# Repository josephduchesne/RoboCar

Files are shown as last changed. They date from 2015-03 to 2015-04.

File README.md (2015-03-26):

# RoboCar

A robot car that uses the following:

[Hardware](../../wiki/Bill-of-Materials)

Note: When cloning use `git clone --recursive git@github.com:josephduchesne/RoboCar.git` to also checkout the usb_cam submodule.

### Third Party Licenses:

 - 3D_Prints/PanTilt is third party, created by Javier Bernal Mayordomo, Miguel Manzano Olmos, and Arturo Serna León under a [Creative Commons - Attribution - Share Alike](http://creativecommons.org/licenses/by-sa/3.0/) license
 - ROS_Workspace/src/usb_cam is third party and by Robert Bosch LLC. under a [BSD licence](https://github.com/bosch-ros-pkg/usb_cam/blob/develop/LICENSE)
 - ROS_Workspace/src/differential_drive is third party and by Jon Stephan under a [GPLv3 license](http://www.gnu.org/licenses/gpl-3.0.html)

### License

For all files not otherwise noted in Third Party Licenses or by license information contained within the files are licensed under:

The MIT License (MIT)

Copyright (c) 2015 Joseph Duchesne

Permission is hereby granted, free of charge, to any person obtaining a copy
of this software and associated documentation files (the "Software"), to deal
in the Software without restriction, including without limitation the rights
to use, copy, modify, merge, publish, distribute, sublicense, and/or sell
copies of the Software, and to permit persons to whom the Software is
furnished to do so, subject to the following conditions:

The above copyright notice and this permission notice shall be included in
all copies or substantial portions of the Software.

THE SOFTWARE IS PROVIDED "AS IS", WITHOUT WARRANTY OF ANY KIND, EXPRESS OR
IMPLIED, INCLUDING BUT NOT LIMITED TO THE WARRANTIES OF MERCHANTABILITY,
FITNESS FOR A PARTICULAR PURPOSE AND NONINFRINGEMENT. IN NO EVENT SHALL THE
AUTHORS OR COPYRIGHT HOLDERS BE LIABLE FOR ANY CLAIM, DAMAGES OR OTHER
LIABILITY, WHETHER IN AN ACTION OF CONTRACT, TORT OR OTHERWISE, ARISING FROM,
OUT OF OR IN CONNECTION WITH THE SOFTWARE OR THE USE OR OTHER DEALINGS IN
THE SOFTWARE.

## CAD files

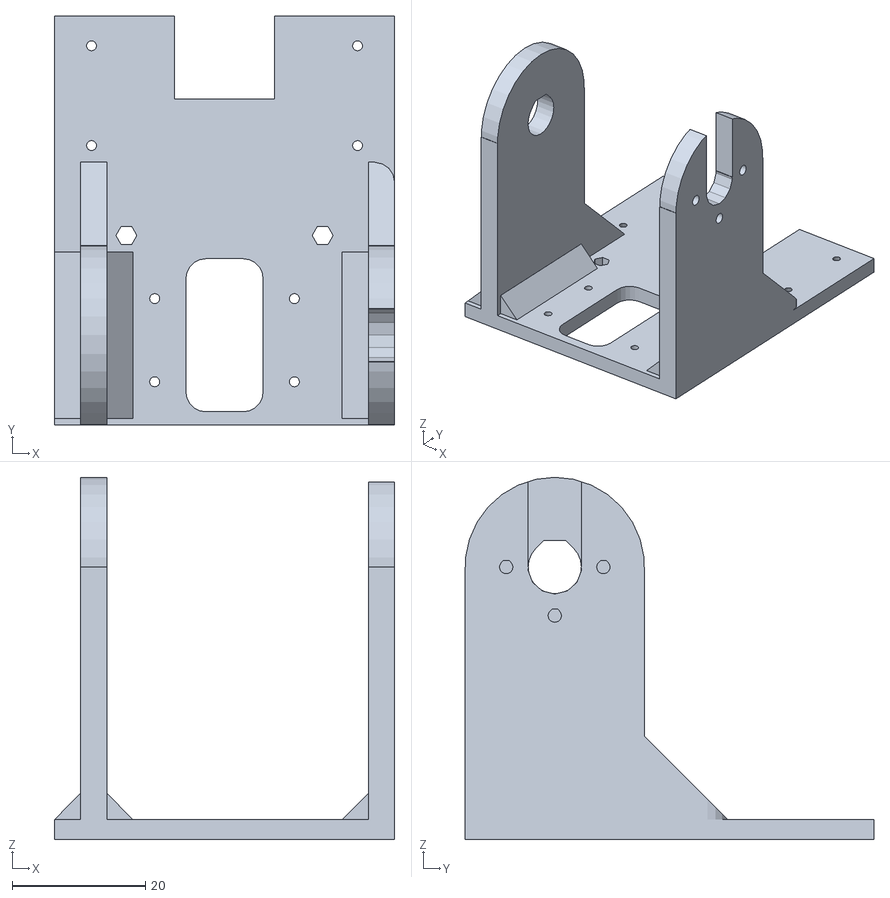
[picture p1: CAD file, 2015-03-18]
3D_Prints/PanTilt/head.stl
51.2 x 61.5 x 54.5

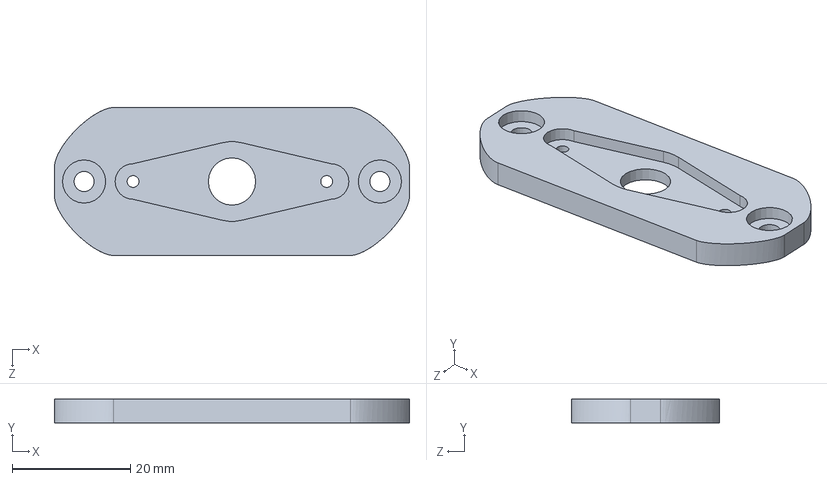
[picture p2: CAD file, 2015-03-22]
3D_Prints/PanTiltBase/BaseTop.SLDPRT
60.0 x 4.00 x 25.0 mm

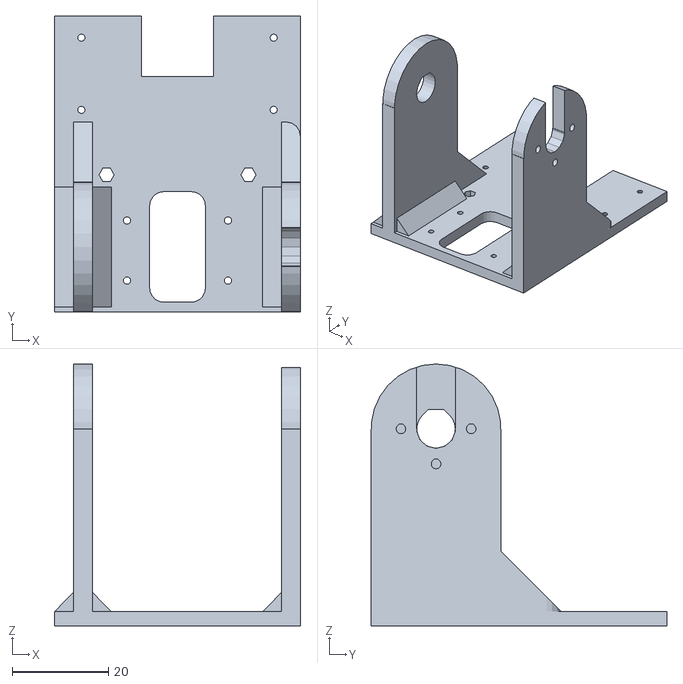
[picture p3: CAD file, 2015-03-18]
3D_Prints/PanTilt/head_fixed.stl
51.2 x 61.5 x 54.5

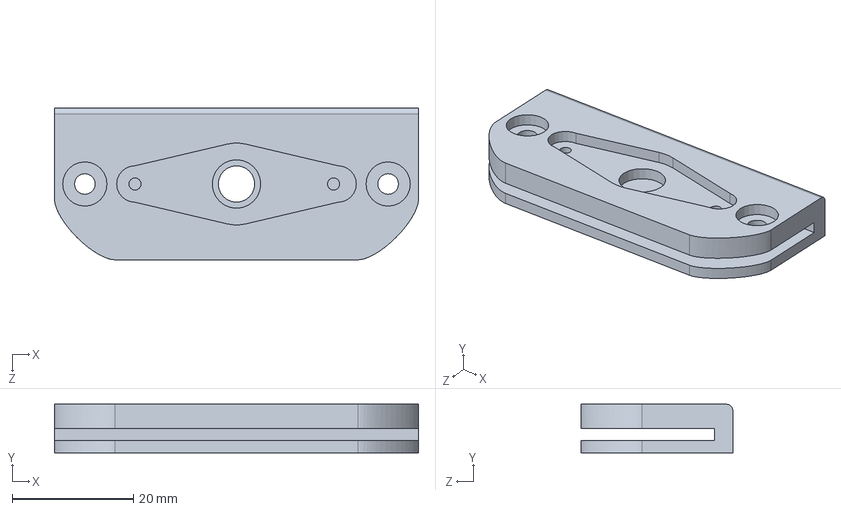
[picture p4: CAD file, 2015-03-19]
3D_Prints/PanTiltBase/Base.SLDPRT
60.0 x 8.00 x 25.0 mm

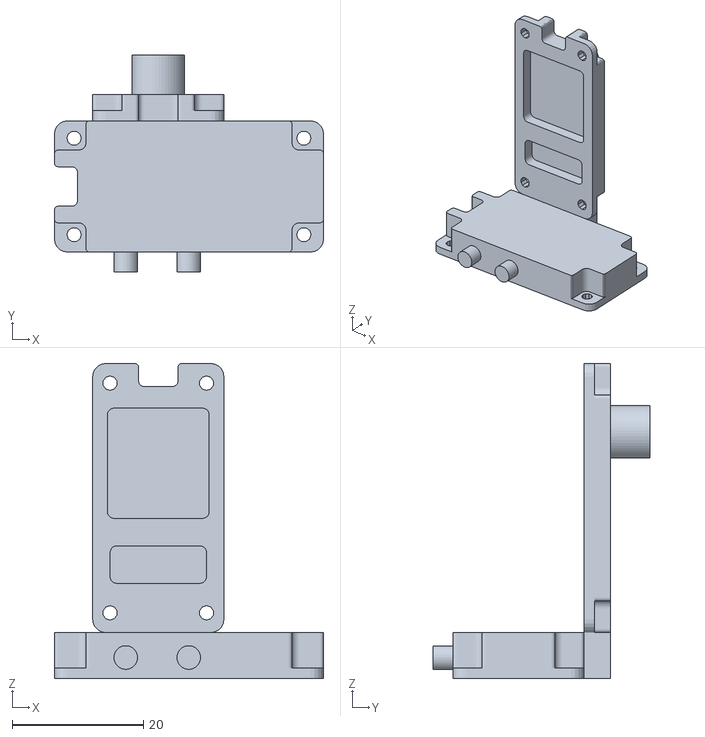
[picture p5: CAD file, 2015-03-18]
3D_Prints/PanTilt/servo_fixed.stl
41.0 x 33.0 x 48.0

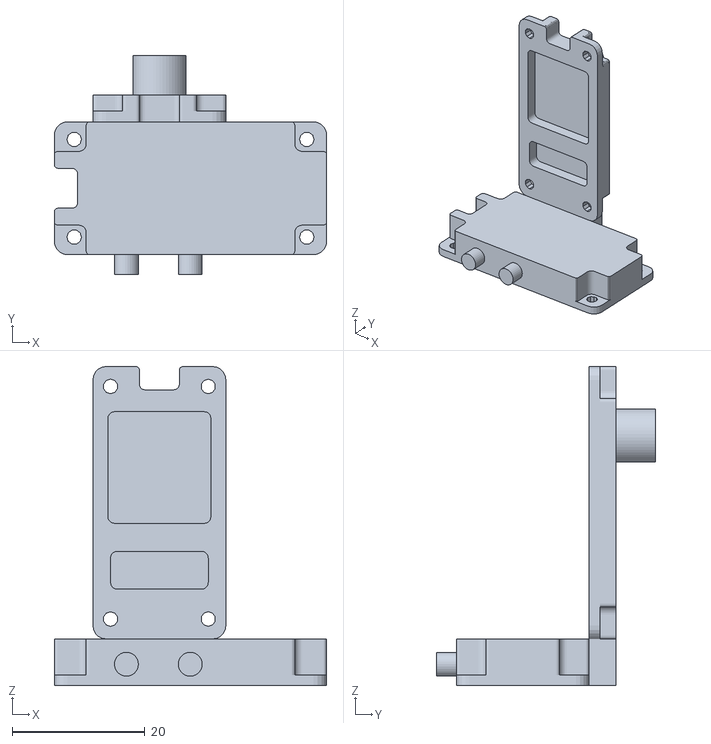
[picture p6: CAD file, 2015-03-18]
3D_Prints/PanTilt/servo.stl
41.0 x 33.0 x 48.0

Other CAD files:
3D_Prints/PanTiltBase/Base.STL
3D_Prints/PanTiltBase/BaseTop.STL

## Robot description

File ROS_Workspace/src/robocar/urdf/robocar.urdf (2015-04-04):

<robot name="robocar">

  <!-- The base platform -->
  <link name="base_link">
    <visual> <!-- Platform top -->
      <origin xyz="0 0 0.079"/>
      <geometry>
        <box size="0.200 0.176 0.002"/>
      </geometry>
      <material name="grey"><color rgba="0.5 0.5 0.5 1"/></material>
    </visual>

    <visual> <!-- platform bottom -->
      <origin xyz="0 0 0.017"/>
      <geometry>
        <box size="0.200 0.113 0.002"/>
      </geometry>
      <material name="dark"/>
    </visual>
    <visual><origin xyz="0.115 0 0.017"/><geometry><box size="0.03 0.18 0.002" /></geometry><material name="dark"/></visual>

    <!-- Sides -->
    <visual><origin xyz="-.066 0.056 0.048"/><geometry><box size="0.04 0.002 0.062" /></geometry><material name="dark"/></visual>
    <visual><origin xyz=".066 0.056 0.048"/><geometry><box size="0.04 0.002 0.062" /></geometry><material name="dark"/></visual>
    <visual><origin xyz="-.066 -0.056 0.048"/><geometry><box size="0.04 0.002 0.062" /></geometry><material name="dark"/></visual>
    <visual><origin xyz=".066 -0.056 0.048"/><geometry><box size="0.04 0.002 0.062" /></geometry><material name="dark"/></visual>

    <visual>
      <origin xyz="0.08 -0.03 0.08" rpy="1.5708 0 1.5708"/>
      <material name="blue"><color rgba="0.1 0.1 1 1"/></material>
      <geometry>
        <mesh scale="0.001 0.001 0.001" filename="package://robocar/../../../3D_Prints/PanTiltBase/BaseTop.STL"/>
      </geometry>
    </visual>
  </link>

  <link name="sensor_arm">
    <visual>
      <origin xyz="-0.01085 0 0.023" />
      <material name="black"><color rgba="0.1 0.1 0.1 1"/></material>
      <geometry> 
        <box size="0.04 0.021 0.037"/>
      </geometry>
    </visual>
    <visual>
      <material name="blue"><color rgba="0.1 0.1 1 1"/></material>
      <origin xyz="-0.01085 0 0.04475" />
      <geometry> 
        <box size="0.04 0.021 0.0065"/>
      </geometry>
    </visual>
    <visual>
      <material name="black"/>
      <origin xyz="-0.006 0.0039 0.0655" />
      <geometry> 
        <box size="0.02 0.042 0.043"/>
      </geometry>
    </visual>
  </link>

  <link name="sensor_platform">
    <visual>
      <origin xyz="0.04 0 0" rpy="-1.5708 0 1.5708"/>
      <material name="blue"><color rgba="0.1 0.1 1 1"/></material>
      <geometry>
        <mesh scale="0.001 0.001 0.001" filename="package://robocar/../../../3D_Prints/PanTilt/head_fixed.stl"/>
      </geometry>
    </visual>
  </link>

  <link name="camera">
    <visual>
      <origin xyz="0 0 0.01" rpy="0 0 0"/>
      <material name="black"/>
      <geometry><cylinder length="0.02" radius="0.007"/></geometry>
    </visual>
  </link>

  <link name="rangefinder">
    <visual>
      <origin xyz="0.019 0.0146 0" rpy="0 -1.5708 0"/>
      <material name="black"/>
      <geometry><cylinder length="0.038" radius="0.0095"/></geometry>
    </visual>
    <visual>
      <origin xyz="0.019 -0.0146 0" rpy="0 -1.5708 0"/>
      <material name="black"/>
      <geometry><cylinder length="0.038" radius="0.0095"/></geometry>
    </visual>
    <visual>
      <origin xyz="0.01 0 0"/>
      <material name="black"/>
      <geometry><box size="0.014 0.04822 0.02"/></geometry>
    </visual>
  </link>

  <link name="laser_scanner">
  </link>

  <joint name="laser_scanner_fixed" type="fixed">
    <parent link="base_link"/>
    <child link="laser_scanner"/>
    <origin xyz="0.0925 0 0.121" rpy="3.141592 0 0"/> 
  </joint>

  <joint name="servo_yaw" type="revolute">
    <parent link="base_link"/>
    <child link="sensor_arm"/>
    <axis xyz="0 0 -1" />
    <limit lower="-1.57" upper="1.57" effort="1" velocity="1" />
    <origin xyz="0.0925 0 0.08"/> 
  </joint>

  <joint name="servo_pitch" type="revolute">
    <axis xyz="0 -1 0"/>
    <limit lower="-0.174" upper="1.745" effort="1" velocity="1"/>
    <parent link="sensor_arm"/>
    <child link="sensor_platform"/>
    <origin xyz="-.006 0.0014 0.078"/> 
  </joint>

  <joint name="camera_offset" type="fixed">
    <parent link="sensor_platform"/>
    <child link="camera"/>
    <origin xyz="0.04 0 0" rpy="-1.5708 0 -1.5708"/> 
  </joint>

  <joint name="rangefinder_offset" type="fixed">
    <parent link="sensor_platform"/>
    <child link="rangefinder"/>
    <origin xyz="0.04 0 -0.038"/> 
  </joint>

  <!-- Wheels Back -->
  <link name="wheel_back_left">
    <visual>
      <origin xyz="0 0 0" rpy="-1.5708 0 0"/>
      <material name="black"><color rgba="0.1 0.1 0.1 1"/></material>
      <geometry><cylinder length="0.018" radius="0.032"/></geometry>
    </visual>
  </link>

  <joint name="wheel_back_left_joint" type="continuous">
    <parent link="base_link"/>
    <axis xyz="0 1 0"/>
    <child link="wheel_back_left"/>
    <origin xyz="-0.0665 0.0745 0.032"/>
  </joint>

  <link name="wheel_back_right">
    <visual>
      <origin xyz="0 0 0" rpy="-1.5708 0 0"/>
      <material name="black"><color rgba="0.1 0.1 0.1 1"/></material>
      <geometry><cylinder length="0.018" radius="0.032"/></geometry>
    </visual>
  </link>

  <joint name="wheel_back_right_joint" type="continuous">
    <parent link="base_link"/>
    <axis xyz="0 1 0"/>
    <child link="wheel_back_right"/>
    <origin xyz="-0.0665 -0.0745 0.032"/>
  </joint>

  <!-- Wheels Front -->
  <link name="wheel_front_left">
    <visual>
      <origin xyz="0 0 0" rpy="-1.5708 0 0"/>
      <material name="black"><color rgba="0.1 0.1 0.1 1"/></material>
      <geometry><cylinder length="0.018" radius="0.032"/></geometry>
    </visual>
  </link>

  <joint name="wheel_front_left_joint" type="continuous">
    <mimic joint="wheel_back_left_joint"/>"
    <parent link="base_link"/>
    <axis xyz="0 1 0"/>
    <child link="wheel_front_left"/>
    <origin xyz="0.0665 0.0745 0.032"/>
  </joint>

  <link name="wheel_front_right">
    <visual>
      <origin xyz="0 0 0" rpy="-1.5708 0 0"/>
      <material name="black"><color rgba="0.1 0.1 0.1 1"/></material>
      <geometry><cylinder length="0.018" radius="0.032"/></geometry>
    </visual>
  </link>

  <joint name="wheel_front_right_joint" type="continuous">
    <mimic joint="wheel_back_right_joint"/>"
    <parent link="base_link"/>
    <axis xyz="0 1 0"/>
    <child link="wheel_front_right"/>
    <origin xyz="0.0665 -0.0745 0.032"/>
  </joint>

</robot>

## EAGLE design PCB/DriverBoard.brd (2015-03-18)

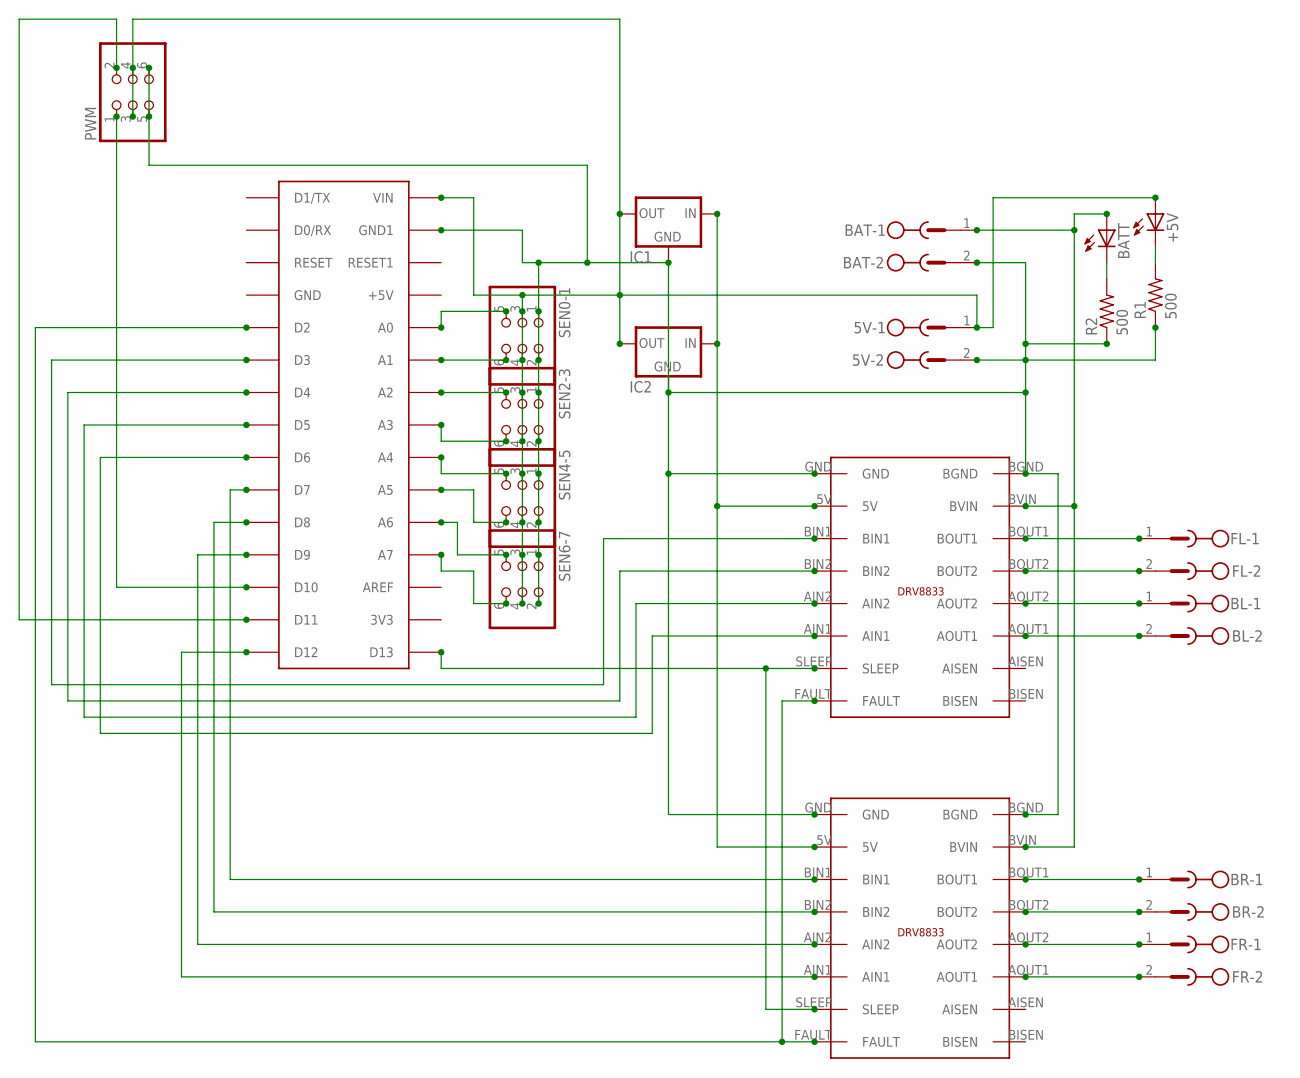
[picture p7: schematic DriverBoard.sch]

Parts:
5V: MSTBV2
+5V: LED5MM
BAT: MSTBV2
BATT: LED5MM
BL: MSTBV2
BR: MSTBV2
FL: MSTBV2
FR: MSTBV2
IC1, IC2: 78XXS
PWM: PINHD-2X3; 2X03
R1, R2: 500; 0207/10
SEN0-1, SEN2-3, SEN4-5, SEN6-7: PINHD-2X3; 2X03
U$1: ARDUINONANO; PDIP-32
U$2, U$3: DRV8833

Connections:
unnamed: 5V.2, BAT.2, IC1.GND, IC2.GND, PWM.5, PWM.6, R1.1, R2.1, SEN0-1.1, SEN0-1.2, SEN2-3.1, SEN2-3.2, SEN4-5.1, SEN4-5.2, SEN6-7.1, SEN6-7.2, U$1.GND1, U$2.BGND, U$2.GND, U$3.BGND, U$3.GND
unnamed: FL.1, U$2.BOUT1
unnamed: FL.2, U$2.BOUT2
unnamed: BL.1, U$2.AOUT2
unnamed: BL.2, U$2.AOUT1
unnamed: BR.1, U$3.BOUT1
unnamed: BR.2, U$3.BOUT2
unnamed: FR.1, U$3.AOUT2
unnamed: FR.2, U$3.AOUT1
unnamed: BAT.1, BATT.A, U$2.BVIN, U$3.BVIN
unnamed: U$1.D13, U$2.SLEEP, U$3.SLEEP
unnamed: IC1.IN, IC2.IN, U$2.5V, U$3.5V
unnamed: U$1.D3, U$2.BIN1
unnamed: U$1.D2, U$2.FAULT, U$3.FAULT
unnamed: U$1.D4, U$2.BIN2
unnamed: U$1.D5, U$2.AIN2
unnamed: U$1.D6, U$2.AIN1
unnamed: U$1.D7, U$3.BIN1
unnamed: U$1.D8, U$3.BIN2
unnamed: U$1.D9, U$3.AIN2
unnamed: U$1.D12, U$3.AIN1
unnamed: PWM.1, U$1.D10
unnamed: PWM.2, U$1.D11
unnamed: 5V.1, +5V.A, IC1.OUT, IC2.OUT, PWM.3, PWM.4, SEN0-1.3, SEN0-1.4, SEN2-3.3, SEN2-3.4, SEN4-5.3, SEN4-5.4, SEN6-7.3, SEN6-7.4, U$1.VIN
unnamed: SEN0-1.5, U$1.A0
unnamed: SEN0-1.6, U$1.A1
unnamed: SEN2-3.5, U$1.A2
unnamed: SEN2-3.6, U$1.A3
unnamed: SEN4-5.5, U$1.A4
unnamed: SEN4-5.6, U$1.A5
unnamed: SEN6-7.5, U$1.A6
unnamed: SEN6-7.6, U$1.A7
unnamed: BATT.K (C), R2.2
unnamed: +5V.K (C), R1.2

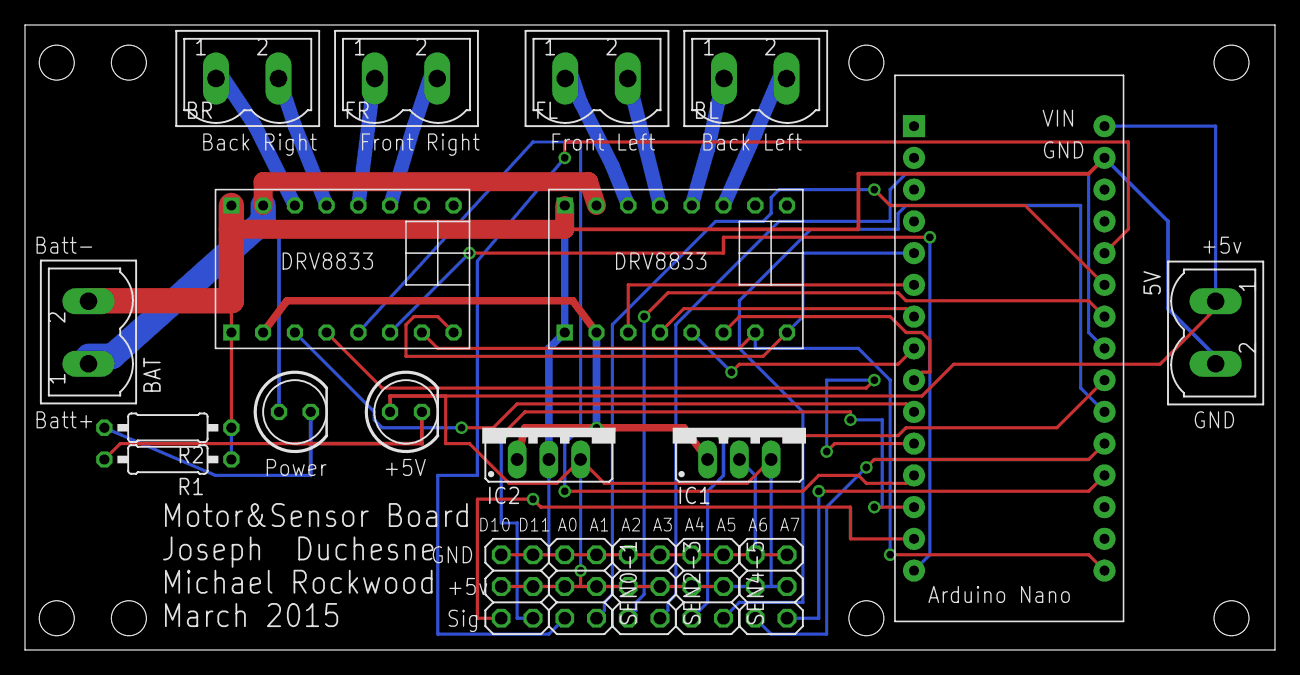
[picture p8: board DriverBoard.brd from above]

Board: 2 copper layers, 100.0 x 50.0 mm, 20 parts (0 on the bottom side), 34 nets.

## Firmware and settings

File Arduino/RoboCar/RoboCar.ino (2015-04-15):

/**
 * Main program
 * Handles serial I/O using a simple g-code inspired ASCII interface
 * Passes off specific motor, servo, and other sensor operations to other files.
 *
 * @author Joseph Duchesne
 */

/* --- incoming serial:  --- */
/* 
 in an any (but normally this) order:
 'L-100\n' to 'L100\n' - left speed
 'R-100\n' to 'R100\n' - right speed
 'M0\n' or 'M1\n' - mode: enable/disable things. LSB: motors, LSB+1: sensor sweep
 'P-10\n' to 'P100\n'  Pitch servo degree
 'Y-45\n' to '45\n' Yaw servo degree
 '#some text' - debugging comments
*/

/* --- outgoing serial: --- */
/* (only when compiled in OUTPUT_ASCII mode)
 in an any (but normally this) order:
 'L-32000\n' to 'L32000\n' the left wheel encoder ticks
 'R-32000\n' to 'R32000\n' the right wheel encoder ticks
 'P-10\n' to 'P100\n'  Pitch servo degree estimate @now
 'Y-45\n' to '45\n' Yaw servo degree estimate @now
 'D0\n' to 'D32000\n' - Rangefinder distance in millimeters
 '#some text' - debugging comments
*/

//decently fast serial
#define SERIAL_BAUD 115200
//ms to wait for more serial data
#define SERIAL_WAIT 2


//variables for controlling sensor data frequency
unsigned long lastOutput = 0;  //miliseconds since arduino start
const int timeBetweenOutputs = 100; //ms between outputting data

int range = 0;
int sensorOffset = 0;
boolean sensorSweep = false;
boolean flushData = false;
#define SENSOR_READINGS 15

// output mode
//#define OUTPUT_ASCII
#define OUTPUT_STRUCT

#ifdef OUTPUT_STRUCT
//note: these are 16 bit ints and should be int16 on PC
struct sensor_packet {
  int servo_pitch;
  int servo_yaw;
  int left_wheel_encoder;
  int right_wheel_encoder;
  int rangefinder_distance;
  int sweep[SENSOR_READINGS*2];
  char end1;
  char end2;
} __attribute__((__packed__));

struct sensor_packet sensorPacket;
#endif

/**
 * Setup function configures all pins, inits libs, resets values
 *
 * @return void
 */
void setup()
{
  motor_setup();
  
  servo_setup();
  
  rangefinder_setup();
  
  //Enable serial communication
  Serial.begin(SERIAL_BAUD); 
  //serial timeout on readBytesUntil()
  Serial.setTimeout(SERIAL_WAIT); //ms
  
  //Serial.println("#Started up");
}

/**
 * Main loop. Checks sensors and outputs readings.
 * 
 * @return void
 */
 
void loop()
{
  readRotaryEncoders(); //for motor data
  
  if (sensorSweep) {
    processSensorSweep();
  } else {
    range = getRange();
  }

  outputSensorData();
}


/**
 * Pseudo-interrupt for new serial data availability
 * Read user input, parse it, and pass that data to the appropriate functions.
 *
 * @return void
 */
void serialEvent(){
  char buff[16] = {0};
  char *data = buff+1;  //pointer offset by 1 to the buffer for the data segment of the command
  int intData;
  
  //read a command line inputs
  Serial.readBytesUntil('\n', buff, 32);
  switch (buff[0]) {
    case 'M': //mode
      intData = String(data).toInt();
      if (intData & 0b1) {  //LSB: 
        //Serial.println("#Motor command run: High");
        setMotorEnable(HIGH);
      } else {
        //Serial.println("#Motor command run: Low");
        setMotorEnable(LOW);
      }
      
      if (intData & 0b10 ) { //byte LSB+1: sensor sweep mode
        sensorSweep = true;
        
      } else {  //not in sweep mode
        sensorSweep = false;
        endSensorSweep();
      }
      break;
    case 'L': //left motor
      //intentional fallthrough to 'R'
    case 'R': //right motor
      intData = String(data).toInt();
      setMotors(buff[0], intData);
      break;
    case 'P': //pitch
      //intentional fallthrough to Yaw
    case 'Y': //yaw
      if ( sensorSweep ) break; //no manual servo movement during sensor sweep
      intData = String(data).toInt();
      setServo(buff[0], intData);
      break;
    case '#': //debug comments
      //we can ignore them
      break;
    default:
      if (buff[0]!='\0') {
        //Serial.print("#Unknown command: ");
        //Serial.println(buff);
      }
      break;
  }
}

/**
 * Tell the communication process to flush a reading
 *
 * @return  void
 */
void setFlushData(){
  flushData = true; 
}

/**
 * Output sensor data periodically via serial port
 *
 * @return void
 */
void outputSensorData(){
  //output sensor value every timeBetweenOutputs
  //or if we're full on sensor readings
  if (millis()-lastOutput < timeBetweenOutputs && sensorOffset<SENSOR_READINGS && !flushData) {
    return;
  }
  lastOutput = millis();
  flushData = false;
  
  #ifdef OUTPUT_ASCII
    //output estimated servo positions
    Serial.print('P');
    Serial.println(estimateServoPosition(0));
    Serial.print('Y');
    Serial.println(estimateServoPosition(1));
    
    //output wheel encoder data
    Serial.print('L');
    Serial.println(getWheelCounter(0));
    Serial.print('R');
    Serial.println(getWheelCounter(1));
    
    //output rangefinder distance data
    
    Serial.print('D');
    Serial.println(range);
  #endif
  
  #ifdef OUTPUT_STRUCT
    sensorPacket.servo_pitch = estimateServoPosition(0);
    sensorPacket.servo_yaw = estimateServoPosition(1);
    sensorPacket.left_wheel_encoder = getWheelCounter(0);
    sensorPacket.right_wheel_encoder = getWheelCounter(1);
    if (sensorSweep) {
      sensorPacket.rangefinder_distance = -sensorOffset;
    } else {
      sensorPacket.rangefinder_distance = range;
    }
    sensorPacket.end1 = 'E';
    sensorPacket.end2 = 'D';
    Serial.write((char *)&sensorPacket, sizeof(sensorPacket));
    
    //clear the sensor readings packet
    for (int i=0; i<SENSOR_READINGS*2;i++) {
      sensorPacket.sweep[i]=0;
    }
    sensorOffset = 0;
  #endif
  

}


/**
 * Write a sensor sweep reading to the sensor packet's data buffer
 *
 * @return void
 */
void setSensorData(float angle, int value){
  if( sensorSweep && sensorOffset<SENSOR_READINGS) {
    int angle_int = (int)(angle*100.0f);
    sensorPacket.sweep[sensorOffset*2] = angle_int;
    sensorPacket.sweep[sensorOffset*2+1] = value;
    sensorOffset++;
  }
}

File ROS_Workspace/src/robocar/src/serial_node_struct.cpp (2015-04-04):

#include "ros/ros.h"
#include <sstream>
#include <string>
#include <iostream>
#include "std_msgs/String.h"
#include "std_msgs/Int16.h"
#include "std_msgs/Float32.h"
#include "sensor_msgs/JointState.h"
#include "sensor_msgs/LaserScan.h"
#include <stdint.h>

#include <boost/algorithm/string.hpp>
#include <tr1/unordered_map>
#include <boost/asio.hpp>
using namespace::boost::asio;  // save tons of typing

std::tr1::unordered_map<std::string, ros::Publisher> pub;
std::tr1::unordered_map<std::string, ros::Subscriber> sub;

serial_port *serial;
serial_port_base::baud_rate serial_baud(115200);
io_service io;

int mode=1;

#define SWEEP_DEGREES_PER_MILLISECOND 0.285
#define SENSOR_READINGS 15
struct sensor_packet {
  int16_t servo_pitch;
  int16_t servo_yaw;
  int16_t left_wheel_encoder;
  int16_t right_wheel_encoder;
  int16_t rangefinder_distance;
  int16_t sweep[SENSOR_READINGS*2];
  uint8_t end1;
  uint8_t end2;
} __attribute__((__packed__));

void parseSensorData( struct sensor_packet sensorPacket){
  std_msgs::Float32 range;
  std_msgs::Int16 left_encoder;
  std_msgs::Int16 right_encoder;
  sensor_msgs::JointState joint_state;
  sensor_msgs::LaserScan laser_scan;

  if(sensorPacket.end1 != 'E' && sensorPacket.end2 != 'D'){
    ROS_INFO("Invalid packet ending");
    return;
  }

  if (sensorPacket.rangefinder_distance != 0) {
    laser_scan.range_min = 0.1f; //http://kb.pulsedlight3d.com/support/solutions/articles/5000548616-lidar-lite-specifications
    laser_scan.range_max = 40.0f;
    laser_scan.angle_min = -0.001;
    laser_scan.angle_max = 0.001;
    laser_scan.angle_increment = 0.002;
    laser_scan.scan_time = 0.0;
    laser_scan.header.frame_id = "rangefinder";
    laser_scan.header.stamp = ros::Time::now();

    //sweep mode packet handling
    if (sensorPacket.rangefinder_distance<0) {
      laser_scan.header.frame_id = "laser_scanner"; 
      int scan_count = -sensorPacket.rangefinder_distance;
      float scan_min = (float)sensorPacket.sweep[0]/100.0f;
      float scan_max = (float)sensorPacket.sweep[(scan_count-1)*2]/100.0f;
      laser_scan.angle_increment = (scan_max-scan_min)/(float)scan_count/180*3.1415;
      laser_scan.time_increment = abs(laser_scan.angle_increment)/SWEEP_DEGREES_PER_MILLISECOND;
      laser_scan.scan_time = 0.8f;
      //subtract 1/2 angle increment since the reading takes place somewhere between time slices
      laser_scan.angle_min = scan_min/180.0*3.1415+laser_scan.angle_increment/2;  //deg to rad
      laser_scan.angle_max = scan_max/180.0*3.1415+laser_scan.angle_increment/2;

      sensorPacket.servo_yaw = laser_scan.angle_max; //max scan angle is the current servo position

      for(int i=0; i<scan_count; i++) {
        //printf("%4.1f, ",(float)sensorPacket.sweep[i*2+1]/100.0f);
        laser_scan.ranges.push_back((float)sensorPacket.sweep[i*2+1]/100.0f); //convert from cm to m
        laser_scan.intensities.push_back((float)sensorPacket.sweep[i*2+1]/100.0f); //convert from cm to m
      }
      //printf("\n");
      
      //printf("Found %d readings: %4.1f to %4.1f deg %4.1f (%4.1f)\n", scan_count, scan_min, scan_max, laser_scan.angle_increment, laser_scan.time_increment); 

    } else { //normal individual rangefinding
      laser_scan.ranges.push_back((float)sensorPacket.rangefinder_distance/100.0f); //convert from cm to m
      laser_scan.ranges.push_back((float)sensorPacket.rangefinder_distance/100.0f); //convert from cm to m
      laser_scan.intensities.push_back((float)sensorPacket.rangefinder_distance/100.0f); //convert from cm to m
      laser_scan.intensities.push_back((float)sensorPacket.rangefinder_distance/100.0f); //convert from cm to m
    }

    pub["laser"].publish(laser_scan);
  }

  //range.data = (float)sensorPacket.rangefinder_distance/100.0f; //convert from cm to m
  //pub["range"].publish(range);

  left_encoder.data = sensorPacket.left_wheel_encoder;
  pub["left_encoder"].publish(left_encoder);

  right_encoder.data = sensorPacket.right_wheel_encoder;
  pub["right_encoder"].publish(right_encoder);

  joint_state.name.push_back("servo_yaw");
  joint_state.position.push_back((float)sensorPacket.servo_yaw/180.0f*3.141592f); //convert to radians
  
  joint_state.name.push_back("servo_pitch");
  joint_state.position.push_back((float)sensorPacket.servo_pitch/180.0f*3.141592f); //convert to radians

  pub["joint_state"].publish(joint_state);
}


boost::asio::streambuf serial_buffer;
void serial_read_handler(const boost::system::error_code& error,std::size_t bytes_transferred){
  //ROS_INFO("Read handler");

  if (!error) {
    const char* serial_bytes = boost::asio::buffer_cast<const char*>(serial_buffer.data());
    serial_buffer.consume(bytes_transferred);

    //72 byte packet + null byte that Arduino seems to like tacking on
    //also sanity checking for the packet ending
    if (bytes_transferred == 72 || bytes_transferred == 73) { 
      struct sensor_packet sensorPacket;
      memcpy(&sensorPacket, serial_bytes, sizeof(sensorPacket));
      parseSensorData(sensorPacket);
      //ROS_INFO("Valid serial length %ld bytes", bytes_transferred);
    } else {
      ROS_INFO("Invalid serial: %ld bytes", bytes_transferred);
    }

  }  else {
    ROS_INFO("Error!");
  }

  //request the next line
  if (ros::ok()) {
    async_read_until(*serial, serial_buffer, "ED", serial_read_handler); 
  } else {
    io.reset();
  }
}

void send_serial_message(char field, int value) {
  //if we were using more than one spinner thread this would have to lock a mutex
  char output[16];
  sprintf(output, "%c%d\n", field, value);

  //ROS_INFO("Writing serial: %s", output);
  boost::asio::write(*serial, boost::asio::buffer(output, strlen(output)));
}

void write_left_motor(std_msgs::Float32 message) {
  send_serial_message('L', (int)message.data);
}

void write_right_motor(std_msgs::Float32 message) {
  send_serial_message('R', (int)message.data);
}

void write_camera_pitch(std_msgs::Int16 message) {
  send_serial_message('P', message.data);
}

void write_camera_yaw(std_msgs::Int16 message) {
  send_serial_message('Y', message.data);
}

void write_mode(std_msgs::Int16 message) {
  mode = message.data; //update the global
  send_serial_message('M', message.data); //set mode
}
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

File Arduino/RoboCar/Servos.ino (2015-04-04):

/**
 * Servo handling functions for control and position estimation
 *
 * @author Joseph Duchesne
 */
 
// Servo lib for camera servos
#include <Servo.h>

//a few useful constants
#define SERVO_PITCH 0
#define SERVO_YAW 1

//fraction multiplier consts
#define NUMERATOR 0
#define DENOMINATOR 1

//sweep constants
#define SWEEP_DEGREES_PER_MILLISECOND 0.285
#define SWEEP_DEGREE_OFFSET -78.326
#define SWEEP_PRE_BLANK 50000
#define SWEEP_POST_BLANK 460000
#define SWEEP_END 800000
int sweep_stage = 0;
short int sweep_direction = 1;  //invert angle sign for backwards sweep
long int sweep_time = 0;

//camera servos: pitch, yaw
const int servoPins[2] = {11,10};
//for pitch, yaw what are the min/max valid values
const int servoRanges[2][2] = {{-10,100}, {-65,65}}; 
//for pitch, yaw what are the microsecond timings for those degrees

const int servoTimings[2][2] = {{710,1920}, {858 ,2242}}; 

//servo position estimation vars/consts
int servoPositionsOld[2] = {0}; 
int servoPositions[2] = {0}; 
int timeOfLastServoChange[2] = {0};
//0.23 sec/60deg @4.8v as per sheed, estimated 0.224 sec/60deg @5v via linear approx.
//for fast and accurate int math, I'm storing a fraction: 0: numerator, 1: denominator
const long int servoDegreesPerMillisecond[2] = {60, 224};
const int maxServoMoveTime = 700; //ms. At 0.224/60deg it would take 672ms to move 180deg.

//servo objects for writing
Servo servos[2];

/**
 * Init servo objects
 * 
 * @return void
 */
void servo_setup() {
  int i;
  
  //attach the servo objects and
  for (i=0;i<2;i++) {
    servos[i].attach(servoPins[i]);
  }
  //move the servos to their home positions (0 degrees horizontal and vertical0
  setServo('P', 0);
  setServo('Y', 0);
}

/**
 * Using the servo's estimated speed, old position, and time since last move command
 * estimate the servo's current position in degrees
 * 
 * @param int offset The servo offset (0 for pitch, 1 for yaw)
 *
 * @return int The current estimated servo position in degrees
 */
int estimateServoPosition(int offset){
  long int delta = millis()-timeOfLastServoChange[offset];
  
  //estimation cutoff to avoid wraparound errors
  if (!timeOfLastServoChange[offset] || delta>maxServoMoveTime) {
    timeOfLastServoChange[offset]=0; //skip estimation in the future
    return servoPositions[offset]; //it's clearly arrived
  }
  
  //multiply the time delta by the degrees/milli fraction to get degree delta
  long int degreeDelta = delta * servoDegreesPerMillisecond[NUMERATOR] / servoDegreesPerMillisecond[DENOMINATOR];
  
  //add or subtract the degree delta and constrain between the old and the new position values
  if (servoPositions[offset]>servoPositionsOld[offset]) { //+ direction
    return constrain(servoPositionsOld[offset]+degreeDelta, servoPositionsOld[offset], servoPositions[offset]);
  } else {  //- direction
    return constrain(servoPositionsOld[offset]-degreeDelta, servoPositions[offset], servoPositionsOld[offset]);
  }
}

/**
 * Set the servos ('P' or 'Y') to an angle
 *
 * @param char dir   The side 'P' for pitch up/down, 'Y' for yaw side to side
 * @param int  angle The angle in degrees
 *
 * @return void
 */
void setServo(char servo, int angle) {
  int microseconds = 0;
  
  int offset = SERVO_PITCH; //pitch defaults to offset 0
  if (servo=='Y') {  //yaw is offset 1
    offset = SERVO_YAW; 
  }
  
  //clamp servo angle between the configured min/max
  angle = constrain(angle, servoRanges[offset][0], servoRanges[offset][1]);
  
  //now calculate the timing 
  microseconds = map(angle,  servoRanges[offset][0], servoRanges[offset][1], servoTimings[offset][0],  servoTimings[offset][1]);

  servos[offset].writeMicroseconds(microseconds);
  
  //update position estimation data
  servoPositionsOld[offset] = estimateServoPosition(offset); 
  servoPositions[offset] = angle; 
  timeOfLastServoChange[offset] = millis();
}

/**
 * Record a sensor sweep reading to the circular buffer
 *
 * @return void
 */
void recordSensorSweepReading(){
  int blocking_range = getRangeNow();
  float milliseconds = (float)(micros() - sweep_time)/1000.0f;
  float angle = milliseconds * SWEEP_DEGREES_PER_MILLISECOND + SWEEP_DEGREE_OFFSET; //This is why we learn y = mx + b
   
  //if we're traveling backwards, the degrees are backwards
  angle = angle * sweep_direction; //this fixes that
  
  setSensorData(angle, blocking_range);  //record the sensor data in the circular output buffer
}

/**
 * A state machine that:
 * - 0: Start the servos moving into forward facing position
 * - 1: First moves the servos into a forward facing position
 * - 2: Then sweep left pre-blanking, after SWEEP_PRE_BLANK
 * - 3: Then sweep left recording data, after SWEEP_POST_BLANK goto 2
 * - 4: Then sweep left post-blanking, then flip direction, reset clock, and goto 1
 *
 * @return void
 */
void processSensorSweep(){
  switch(sweep_stage){
    case 0: //reset to start position from wherever, then get into case 1,2,3 loop
      setServo('P', 0);  //pitch level with horizon
      setServo('Y', servoRanges[SERVO_YAW][0]);  //move the low side
      sweep_direction = -1;  //initially moving towards negative
      sweep_time = micros();
      sweep_stage = 1;
      break;
      
    case 1: //wait for move to be done
      if (micros() - sweep_time >= SWEEP_END) {  //give it the max time to arrive
        sweep_time = micros();
        sweep_direction *= -1; //reverse sweep direction
        sweep_stage = 2;
        setServo('Y', servoRanges[SERVO_YAW][(1+sweep_direction)/2]); //move to the other side
      }
      break;
      
    case 2: //skip the spin up
      if (micros() - sweep_time >= SWEEP_PRE_BLANK) {
          sweep_stage = 3;
      }
      break;
      
    case 3: //RECORD while moving at a constant angular velocity
      recordSensorSweepReading();
      if (micros() - sweep_time >= SWEEP_POST_BLANK) {
          setFlushData();
          sweep_stage = 1;
      }
      break;
  }
}

void endSensorSweep(){
  sweep_stage = 0; 
  setServo('P', 0);  //pitch level with horizon
  setServo('Y', 0);  //pitch level with horizon
}

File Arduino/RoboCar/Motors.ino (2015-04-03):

/**
 * Servo handling functions for control and position estimation
 *
 * @author Joseph Duchesne
 */
 

// We need the soft pwm lib since we're not using hardware PWM pins for the motors
#include <SoftPWM.h>
#include <SoftPWM_timer.h>

//pinout:
const int motorEnable = 13; // LED connected to digital pin 13

//if this goes low, one of the motor drivers is having a bad day
const int motorError = 2;

//used by the rotary encoders to know if we should increment/decrement
static int motorDirections[2] = {0, 0}; //stopped, +1 for forward, -1 for back

//wheelEncoders: back left, back right
const int wheelEncoders[2] = {A2,A3};
boolean wheelEncoderValues[2] = {false, false}; //logic levels for wheel encoders
long int wheelEncoderCounters[2] = {0,0};  //number of counts for wheel encoders

unsigned long lastEncoderRead = 0;  //miliseconds since arduino start
//the motors can spin at about 1.3rev/sec. With 20 state changes/rev 
//lets poll this at ~5x that which should incidentally debounce things
const int timeBetweenEncoderReads = 8; //ms, 0.008s


//Front left, back left, back right, front right {forward, reverse}
const int motors[4][2] = {{3,4},{5,6},{7,8},{9,12}};

/**
 * Init motor encoders and output
 * 
 * @return void
 */
void motor_setup() {
  //disable motor drivers
  pinMode(motorEnable, OUTPUT);      // sets the digital pin as output
  SoftPWMBegin();
  
  //set motors
  int i,j;
  for (i=0;i<4;i++) {
    for (j=0;j<2;j++) {
      SoftPWMSet(motors[i][j], 0);
    }
  }
  
  //configure wheel encoders for reading
  for(i=0;i<2;i++){
    pinMode(wheelEncoders[i], INPUT);
  } 
}


/**
 * Set the motors ('L' or 'R') to a speed (-100 through 100)
 *
 * @param char dir   The side 'L' for left, 'R' for right
 * @param int  speed The speed as a percentage from -100 to 100
 *
 * @return void
 */
void setMotors(char side, int speed) {
  int offset = 0; //left motors are 0, 1
  if (side=='R') {  //right motors are 2,3
    offset = 2; 
  }
  
  //Serial.println("#M");
  /*
  Serial.print("#Motors driving: ");
  Serial.print(side);
  Serial.print(" side: ");
  Serial.print(speed);
  Serial.println("speed");*/
  
  if (speed>0) { //forward
    SoftPWMSetPercent(motors[offset+0][0], speed);
    SoftPWMSetPercent(motors[offset+0][1], 0);
    SoftPWMSetPercent(motors[offset+1][0], speed);
    SoftPWMSetPercent(motors[offset+1][1], 0);
    motorDirections[offset/2] = 1;  
  } else if (speed <0) {  //reverse
    SoftPWMSetPercent(motors[offset+0][0], 0);
    SoftPWMSetPercent(motors[offset+0][1], -1*speed);
    SoftPWMSetPercent(motors[offset+1][0], 0);
    SoftPWMSetPercent(motors[offset+1][1], -1*speed);
    motorDirections[offset/2] = -1;
  } else { //stop
     //direction left alone
     SoftPWMSetPercent(motors[offset+0][0], 0);
     SoftPWMSetPercent(motors[offset+0][1], 0);
     SoftPWMSetPercent(motors[offset+1][0], 0);
     SoftPWMSetPercent(motors[offset+1][1], 0);
  }
}

/**
 * Enable/disable motor drivers
 * 
 * @param boolean value HIGH or LOW to enable/disable motors
 *
 * @return void
 */
void setMotorEnable(boolean value) {
  wheelEncoderCounters[1] = wheelEncoderCounters[0] = 0;  //clear the encoder counters, we've restarted
   
  digitalWrite(motorEnable, value); 
}

/**
 * Read rotary encoder values to try to estimate distance traveled
 *
 * @return void
 */
void readRotaryEncoders() {
  //output sensor value every timeBetweenOutputs
  if (millis()-lastEncoderRead < timeBetweenEncoderReads) {
    return; 
  } 
  lastEncoderRead = millis();
  
  //iterate left and right encoders
  for (int i=0; i<2; i++) {
    //if the value has changed
    if (digitalRead(wheelEncoders[i])!=wheelEncoderValues[i]) {
      wheelEncoderValues[i] = digitalRead(wheelEncoders[i]);
      wheelEncoderCounters[i] += motorDirections[i]; //increment/decrement as needed
    }
  }
}

/**
 * Return the number of wheel encoder ticks for a wheel
 * 
 * @param int wheel left (0) or right(1) wheels
 * 
 * @return long int Ticks each wheel has undergone
 */
long int getWheelCounter(int wheel) {
  return wheelEncoderCounters[wheel];
}

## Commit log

2015-03-19 Added base for the pan tilt system
    [Base.SLDPRT, Base.STL]
2015-03-22 Added pan/tilt base and updated arduino software
    Pan/tilt base 3d model for Futaba S3003 linear servo horn to mount the
    pan/tilt to the bot.
    Also updated arduino software to support pan/tilt
    [BaseTop.SLDPRT, BaseTop.STL]
2015-03-23 Servo position estimation
    Added servo position estimation and split motors and servos into
    separate files.
2015-03-24 added a basic temporary prereqs script, and added a camera launcher
2015-03-24 Switched startup chime to comment
2015-03-25 Tweaked servo values
2015-03-26 added camera test launchfile
2015-03-27 Fixed the terribly LIDAR reading code
    [Rangefinder.ino, RoboCar.ino, Servos.ino]
2015-03-27 fixed a few things
    [robocar_serial_node.py]
2015-03-27 finished C++ serial node, added camera pit/yaw to py and C++ serial nodes
2015-03-27 added pid test launchfile
2015-03-27 fixed PID subscriptions
2015-03-27 better launch pid params
2015-03-27 Tweaked arduino code
2015-03-27 renamed serial node, commented out pid debug, reduced queue sizes to 1 mostly, and fixed bug in python serial node
    [joyctl.py, serial_node.cpp, serial_node.py]
2015-03-27 Slowed down arduino outputs
2015-03-28 increased PID rate
2015-03-28 added serial node struct and switched all launchfiles to it
2015-03-28 modeled robot using urdf for rviz
    [robocar.urdf]
2015-03-28 added support for moving servos with joyctl and fixed a bug with pitch estimate publishing
    [joyctl.py, serial_node_struct.cpp]
2015-03-28 added laser scan to rviz, serial_node_struct, fixed a relative pathing issue, and added dependency on sensor_msgs
    [robocar.urdf]
2015-03-29 fixed urdf camera orientation, added camera calibration yaml
    [robocar.urdf]
2015-04-03 Added laser scan sweep mode
    M2/M3 (2nd bit on M command) now sets sweep mode, M0/M1 to disable. This
    performs repeated laser scans back and forth with the yaw servo.
2015-04-03 added mode toggle on joystick button 1
2015-04-03 fixed struct size bug
    [serial_node_struct.cpp]
2015-04-04 handle laser scan properly
2015-04-04 tweaked rviz, updated URDF fixed laser scan base
    [robocar.urdf]
